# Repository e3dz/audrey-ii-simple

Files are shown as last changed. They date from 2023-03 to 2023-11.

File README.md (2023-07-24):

# Audrey II

Audrey II is a droning horroscape generator instrument for the Daisy Seed + SynthUX Simple platform
based on simple physical modeling principles.

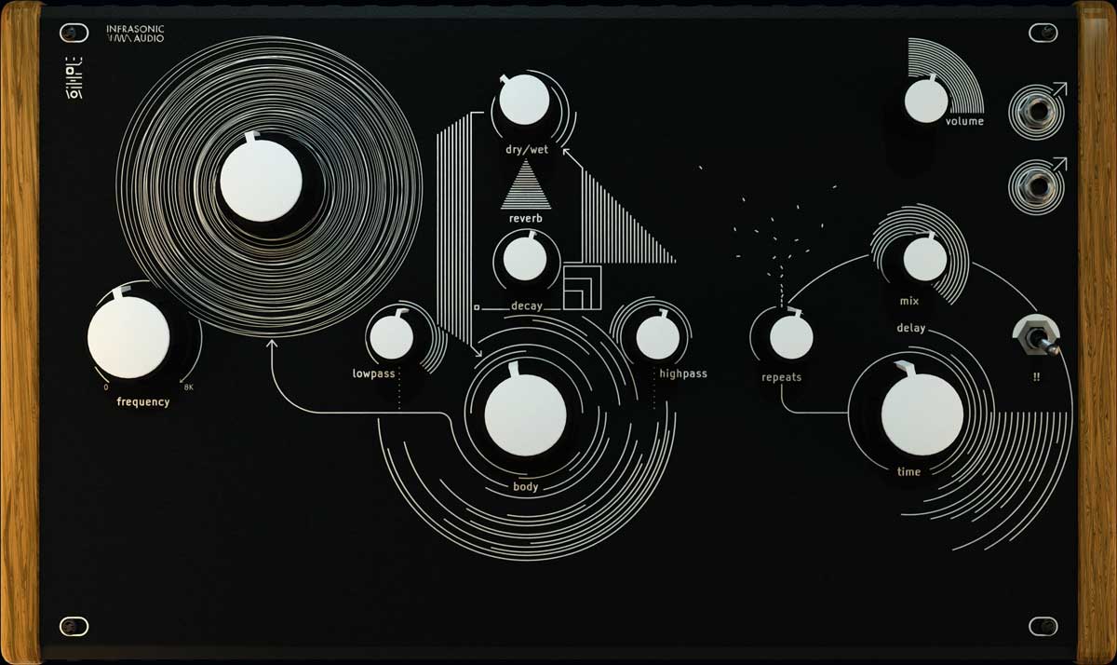
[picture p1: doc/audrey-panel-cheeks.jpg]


_The vortex beckons you. With trembling fingers, you ever so gently turn the mysterious knob within.
Gently, at first, the engine stirs and the arcane beast within awakens. Your pulse quickens.
It wants more. As you turn the knob further, a chilling draft fills the room. The tone swells.
You attempt to appease it with the other controls, but its cries merely evolve into something new,
 equally terrifying and beautiful. A tear rolls down your cheek. The prophecy is fulfilled._

## Overview

At the core of Audrey II is a [Karplus Strong](https://en.wikipedia.org/wiki/Karplus%E2%80%93Strong_string_synthesis)
string model, one of simplest  possible string-waveguide physical modeling implementations.

The output tap of the string model feeds into a soft-clipping distortion, then a reverb,
then into fairly gentle linear lowpass and highpass EQ filters, and then finally into a
longer delay line (aka "body") before being fed back into the string model.

Rather than the typical noise burst or other excitation signals used in "realistic" K-S
models, Audrey-II simply feeds the string a constant stream of inaudible white noise.
As a result, no sound is produced by the instrument until the outer feedback gain is increased
(the big knob with all the circles around it).

This causes the aforementioned feedback loop to activate and a signal begins to build. The
rough fundamental pitch of the sound is determined by the K-S string delay line length
("frequency") and the overtones which resonate and the overall timbre of the sound is
determined by the rest of the controls in the outer feedback loop.

Finally, the output of this section goes through a tape-like delay with a fairly long
maximum delay time and a feedback control designed to deliberately produce infinitely
growing/saturating feedback, for creative distorted warping and warbling possibilities.

## Simple Kit Build Guide

### [🛠️ Build Guide](https://github.com/infrasonicaudio/audrey-ii-simple/wiki/Building-the-Audrey-II-Simple-Kit)

## Flashing the Daisy Seed

The easiest way to program an assembled Audrey II is with a pre-built binary file.
This does not require setting up the toolchain or compiling any code.

1. Download the latest `.bin` file from the [releases page](https://github.com/infrasonicaudio/audrey-ii-simple/releases)
2. Go to the [Daisy Web Programmer](https://electro-smith.github.io/Programmer/) in Google Chrome
3. Connect the Daisy Seed to your computer with a USB cable (double check that the cable you use actually carries data, not just power)
4. Follow the Help instructions at the top to put the Daisy Seed into bootloader mode and connect it to the web programmer
5. In the section labeled "Or select a file from your computer..." click "Browse" and open the `.bin` file you downloaded in step 1
6. At the bottom click "Program" and wait for the process to complete

## Firmware Hacking

1. Install the [Daisy Toolchain](https://github.com/electro-smith/DaisyWiki/wiki/1.-Setting-Up-Your-Development-Environment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) for your operating system
2. Clone this repository and its submodules
3. Open the repository folder in VScode
4. Run the "build_all" task (see: [VSCode tasks](https://code.visualstudio.com/Docs/editor/tasks)). You only have to build_all once to ensure the libraries are built, after that you can do just "build"
5. After a successful build you can flash the Seed using the "program" or "program-dfu" task depending on whether you're using an STLink or DFU over USB

Or if you don't want to use VSCode, you can run standard gnu `make` in the root of `lib/libDaisy`,
`lib/DaisySp` and finally in the repository root. Then you can use `make program` or
`make program-dfu` to flash the built binary.

## License

This project is licensed under the MIT License. See `LICENSE` for details.

This project uses code from DaisySP, libDaisy, RtMidi, and RtAudio which are all
also licensed under the MIT license. The relevant license documentation and
source code for these can be found in `lib/` as git submodules.

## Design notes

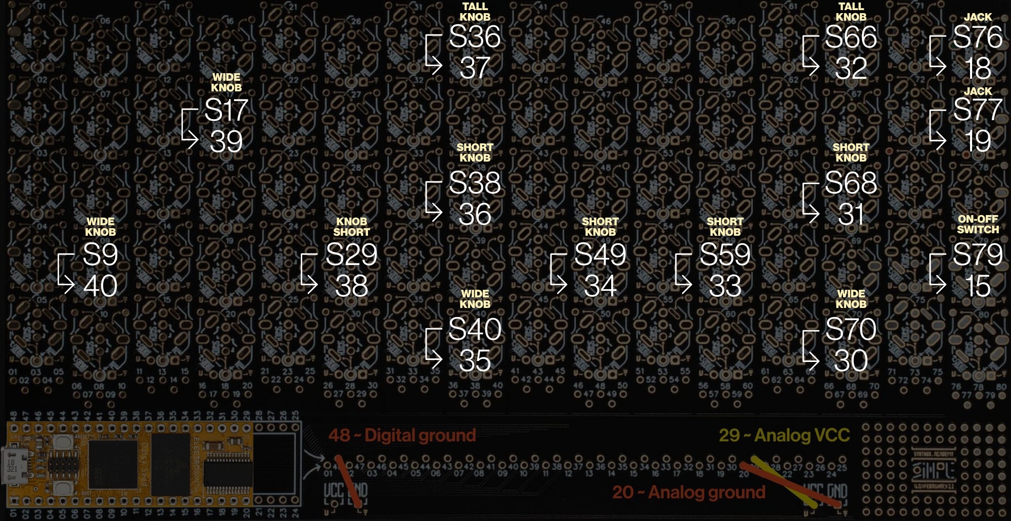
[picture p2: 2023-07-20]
doc/audrey-simple-routing.jpg

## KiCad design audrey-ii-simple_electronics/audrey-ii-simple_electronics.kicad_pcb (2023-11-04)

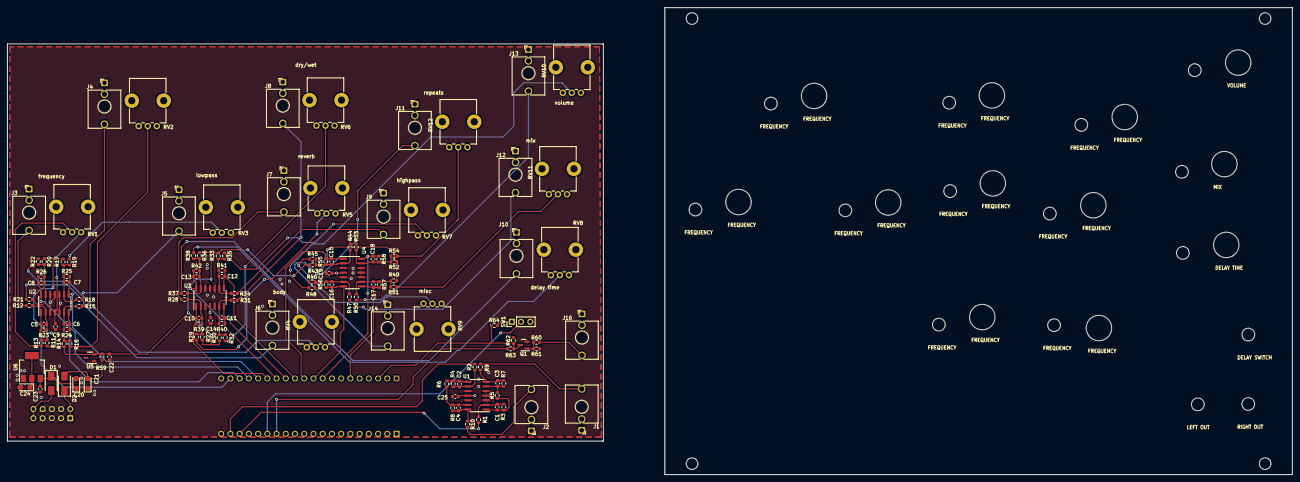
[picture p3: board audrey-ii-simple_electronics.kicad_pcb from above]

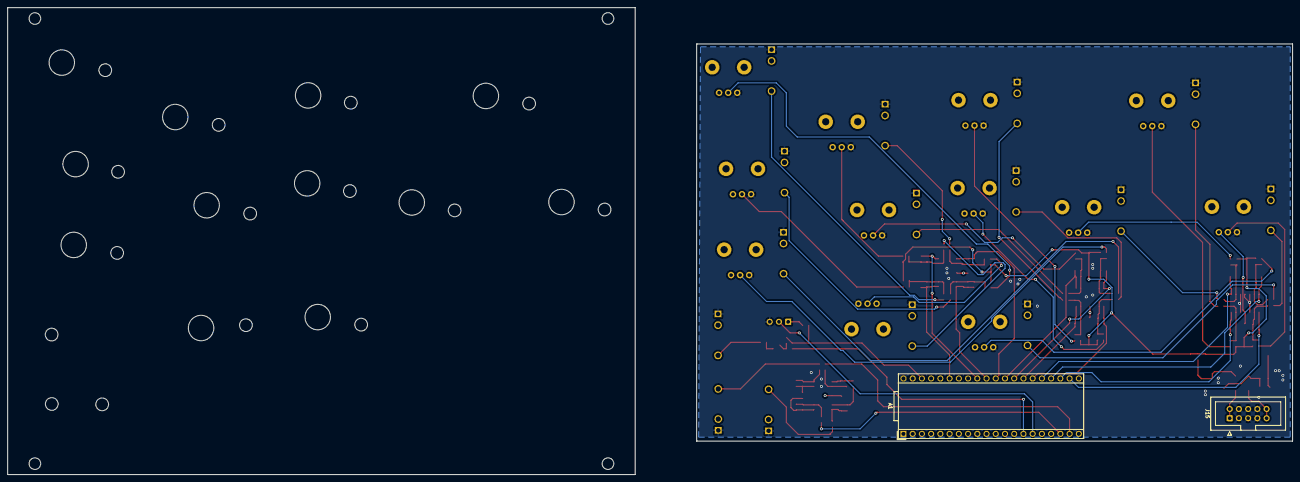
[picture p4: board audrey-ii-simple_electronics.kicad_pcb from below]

Board: 4 copper layers, 164.0 x 109.3 mm, 128 parts (2 on the bottom side), 75 nets.

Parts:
A1: Electrosmith_Daisy_Seed_Rev4; Electrosmith_Daisy_Seed
C1, C2, C3, C4: 47p; C_0603_1608Metric
C5, C6, C7, C8, C10, C11, C12, C13, C15, C16, C17, C18: 10n; C_0603_1608Metric
C9, C14, C19, C22, C23, C25: 100n; C_0603_1608Metric
C20, C21: 22u; CP_EIA-3216-18_Kemet-A
C24: 10uF; CP_EIA-3216-18_Kemet-A
D1, D2: D_Small; D_SMA
J1, J2, J16: DAC_OUT_2; Jack_3.5mm_QingPu_WQP-PJ398SM_Vertical_CircularHoles
J3, J7, J11: CV_1; Jack_3.5mm_QingPu_WQP-PJ398SM_Vertical_CircularHoles
J4, J8, J12: CV_2; Jack_3.5mm_QingPu_WQP-PJ398SM_Vertical_CircularHoles
J5, J9, J13: CV_3; Jack_3.5mm_QingPu_WQP-PJ398SM_Vertical_CircularHoles
J6, J10, J14: CV_4; Jack_3.5mm_QingPu_WQP-PJ398SM_Vertical_CircularHoles
J15: Conn_02x05_Odd_Even; IDC-Header_2x05_P2.54mm_Vertical
Q1: MMBT3904; SOT-23
R1, R2, R62: 10k; R_0603_1608Metric
R3, R4, R5, R6, R7, R8, R12, R15, R18, R21, R28, R31, R34, R37, R44, R47, R50, R53, R60: 100k; R_0603_1608Metric
R9, R10, R63, R64: 1k; R_0603_1608Metric
R11, R14, R17, R20, R27, R30, R33, R36, R43, R46, R49, R52: 200k; R_0603_1608Metric
R13, R16, R19, R22, R23, R24, R25, R26, R29, R32, R35, R38, R39, R40, R41, R42, R45, R48, R51, R54, R55, R56, R57, R58: 66k5; R_0603_1608Metric
R59: 2k; R_0603_1608Metric
R61: 1M; R_0603_1608Metric
RV1, RV2, RV3, RV4, RV5, RV6, RV7, RV8, RV9, RV10, RV11, RV12: M-10K-B-D; Potentiometer_Alps_RK09K_Single_Vertical
SW1: SW_SPDT; PinHeader_1x03_P2.54mm_Vertical
U1: TL074; SOIC-14_3.9x8.7mm_P1.27mm
U2, U3, U4: MCP6004; SOIC-14_3.9x8.7mm_P1.27mm
U5: LM4040-10V; SOT-23-3
U6: LD1117S50TR_SOT223; SOT-223-3_TabPin2

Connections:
+3.3V: A1.38 (3V3_D), R62.2, R64.1
+3.3VA: A1.21 (3V3_A), C9.1, C14.1, C19.1, C25.1, RV1.1, RV2.1, RV3.1, RV4.1, RV5.1, RV6.1, RV7.1, RV8.1, RV9.1, RV10.1, RV11.1, RV12.1, U1.11 (V-), U2.4 (V+), U3.4 (V+), U4.4 (V+)
+5V: C24.1, U6.2 (VO)
-10V_REF: C22.1, R11.1, R14.1, R17.1, R20.1, R27.1, R30.1, R33.1, R36.1, R43.1, R46.1, R49.1, R52.1, R59.1, U5.2 (A)
/ADCBufferIn1/ADC_1: A1.26 (ADC_4), C10.1, R39.2, U3.1
/ADCBufferIn1/ADC_2: A1.27 (ADC_5), C11.1, R40.2, U3.7
/ADCBufferIn1/ADC_3: A1.29 (DAC_OUT2), C12.1, R41.2, U3.8
/ADCBufferIn1/ADC_4: A1.28 (ADC_6), C13.1, R42.2, U3.14
/ADCBufferIn1/KNOB_1: R29.1, RV5.2
/ADCBufferIn1/KNOB_2: R32.1, RV6.2
/ADCBufferIn1/KNOB_3: R35.1, RV7.2
/ADCBufferIn1/KNOB_4: R38.1, RV8.2
/ADCBufferIn2/ADC_1: A1.30 (DAC_OUT1), C15.1, R55.2, U4.1
/ADCBufferIn2/ADC_2: A1.31 (SAI2_MCLK), C16.1, R56.2, U4.7
/ADCBufferIn2/ADC_3: A1.35 (SAI2_SCK), C17.1, R57.2, U4.8
/ADCBufferIn2/ADC_4: A1.32 (SAI2_SD_B), C18.1, R58.2, U4.14
/ADCBufferIn2/KNOB_1: R45.1, RV9.2
/ADCBufferIn2/KNOB_2: R48.1, RV10.2
/ADCBufferIn2/KNOB_3: R51.1, RV11.2
/ADCBufferIn2/KNOB_4: R54.1, RV12.2
/ADCBufferIn/ADC_1: A1.22 (ADC_0), C5.1, R23.2, U2.1
/ADCBufferIn/ADC_2: A1.23 (ADC_1), C6.1, R24.2, U2.7
/ADCBufferIn/ADC_3: A1.25 (ADC_3), C7.1, R25.2, U2.8
/ADCBufferIn/ADC_4: A1.24 (ADC_2), C8.1, R26.2, U2.14
/ADCBufferIn/KNOB_1: R13.1, RV1.2
/ADCBufferIn/KNOB_2: R16.1, RV2.2
/ADCBufferIn/KNOB_3: R19.1, RV3.2
/ADCBufferIn/KNOB_4: R22.1, RV4.2
/Audio Buffer Out/AUDIO_OUT_L: A1.18 (AUDIO_OUT_1), R1.1
/Audio Buffer Out/AUDIO_OUT_R: A1.19 (AUDIO_OUT_2), R2.1
/GPIOIn/In: A1.14 (USART1_TX), R63.1
/SPDT/I/O: A1.15 (USART1_RX), SW1.2 (B)
GND: A1.20 (AGND), A1.40 (DGND), C9.2, C14.2, C19.2, C20.2, C21.1, C22.2, C23.2, C24.2, C25.2, J1.S, J2.S, J3.S, J4.S, J5.S, J6.S, J7.S, J8.S, J9.S, J10.S, J11.S, J12.S, J13.S, J14.S, J15.3, J15.4, J15.5, J15.6, J15.7, J15.8, J16.S, Q1.2 (E), R61.1, RV1.3, RV2.3, RV3.3, RV4.3, RV5.3, RV6.3, RV7.3, RV8.3, RV9.3, RV10.3, RV11.3, RV12.3, SW1.3 (C), U1.3 (+), U1.4 (V+), U1.5 (+), U1.10 (+), U1.12 (+), U2.3 (+), U2.5 (+), U2.10 (+), U2.11 (V-), U2.12 (+), U3.3 (+), U3.5 (+), U3.10 (+), U3.11 (V-), U3.12 (+), U4.3 (+), U4.5 (+), U4.10 (+), U4.11 (V-), U4.12 (+), U5.1 (K), U6.1 (GND)
unnamed: C1.1, R3.2, R5.1, U1.1
unnamed: C2.1, R4.2, R6.1, U1.8
unnamed: C3.1, R7.2, R9.1, U1.7
unnamed: C4.1, R8.2, R10.1, U1.14
unnamed: D1.2 (A), J15.9, J15.10
unnamed: D2.1 (K), J15.1, J15.2
unnamed: J1.T, R9.2
unnamed: J2.T, R10.2
unnamed: J3.T, R12.1
unnamed: J4.T, R15.1
unnamed: J5.T, R18.1
unnamed: J6.T, R21.1
unnamed: J7.T, R28.1
unnamed: J8.T, R31.1
unnamed: J9.T, R34.1
unnamed: J10.T, R37.1
unnamed: J11.T, R44.1
unnamed: J12.T, R47.1
unnamed: J13.T, R50.1
unnamed: J14.T, R53.1
unnamed: J16.T, R60.1
unnamed: Q1.1 (B), R60.2, R61.2
unnamed: Q1.3 (C), R62.1, R63.2
unnamed: R64.2, SW1.1 (A)
unnamed: C1.2, R1.2, R3.1, U1.2 (-)
unnamed: C3.2, R5.2, R7.1, U1.6 (-)
unnamed: C2.2, R2.2, R4.1, U1.9 (-)
unnamed: C4.2, R6.2, R8.1, U1.13 (-)
unnamed: C5.2, R11.2, R12.2, R13.2, R23.1, U2.2 (-)
unnamed: C6.2, R14.2, R15.2, R16.2, R24.1, U2.6 (-)
unnamed: C7.2, R17.2, R18.2, R19.2, R25.1, U2.9 (-)
unnamed: C8.2, R20.2, R21.2, R22.2, R26.1, U2.13 (-)
unnamed: C10.2, R27.2, R28.2, R29.2, R39.1, U3.2 (-)
unnamed: C11.2, R30.2, R31.2, R32.2, R40.1, U3.6 (-)
unnamed: C12.2, R33.2, R34.2, R35.2, R41.1, U3.9 (-)
unnamed: C13.2, R36.2, R37.2, R38.2, R42.1, U3.13 (-)
unnamed: C15.2, R43.2, R44.2, R45.2, R55.1, U4.2 (-)
unnamed: C16.2, R46.2, R47.2, R48.2, R56.1, U4.6 (-)
unnamed: C17.2, R49.2, R50.2, R51.2, R57.1, U4.9 (-)
unnamed: C18.2, R52.2, R53.2, R54.2, R58.1, U4.13 (-)
VCC: C20.1, C23.1, D1.1 (K), U6.3 (VI)
VEE: C21.2, D2.2 (A), R59.2

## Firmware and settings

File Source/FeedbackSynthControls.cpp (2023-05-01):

#include "FeedbackSynthControls.h"
#include <functional>

using namespace infrasonic;
using namespace infrasonic::FeedbackSynth;
using namespace daisy;

////////////// SIMPLE X DAISY PINOUT CHEATSHEET ///////////////

// 3v3           29  |       |   20    AGND
// D15 / A0      30  |       |   19    OUT 01
// D16 / A1      31  |       |   18    OUT 00
// D17 / A2      32  |       |   17    IN 01
// D18 / A3      33  |       |   16    IN 00
// D19 / A4      34  |       |   15    D14
// D20 / A5      35  |       |   14    D13
// D21 / A6      36  |       |   13    D12
// D22 / A7      37  |       |   12    D11
// D23 / A8      38  |       |   11    D10
// D24 / A9      39  |       |   10    D9
// D25 / A10     40  |       |   09    D8
// D26           41  |       |   08    D7
// D27           42  |       |   07    D6
// D28 / A11     43  |       |   06    D5
// D29           44  |       |   05    D4
// D30           45  |       |   04    D3
// 3v3 Digital   46  |       |   03    D2
// VIN           47  |       |   02    D1
// DGND          48  |       |   01    D0

// TODO: Add footprint numbers to these

static constexpr daisy::Pin kFreqKnobAdcPin             = daisy::seed::A10; // Simple bottom pin 40
static constexpr daisy::Pin kFeedbackGainKnobPin        = daisy::seed::A9;  // Simple bottom pin 39
static constexpr daisy::Pin kFeedbackBodyKnobPin        = daisy::seed::A5;  // Simple bottom pin 35
static constexpr daisy::Pin kFeedbackLowpassKnobAdcPin  = daisy::seed::A8;  // Simple bottom pin 38
static constexpr daisy::Pin kFeedbackHighpassKnobAdcPin = daisy::seed::A4;  // Simple bottom pin 34
static constexpr daisy::Pin kRevMixKnobAdcPin           = daisy::seed::A7;  // Simple bottom pin 37
static constexpr daisy::Pin kRevDecayKnobAdcPin         = daisy::seed::A6;  // Simple bottom pin 36
static constexpr daisy::Pin kEchoSendKnobAdcPin         = daisy::seed::A1;  // Simple bottom pin 31
static constexpr daisy::Pin kEchoTimeKnobAdcPin         = daisy::seed::A0;  // Simple bottom pin 30
static constexpr daisy::Pin kEchoFeedbackKnobAdcPin     = daisy::seed::A3;  // Simple bottom pin 33
static constexpr daisy::Pin kOutputVolumeAdcPin         = daisy::seed::A2;  // Simple bottom pin 32
static constexpr daisy::Pin kDelaySwitchPin             = daisy::seed::D14; // Simple bottom pin 15

void Controls::Init(DaisySeed &hw, Engine &engine) {
    params_.Init(hw.AudioSampleRate() / hw.AudioBlockSize());
    del_sw_.Init(
        static_cast<dsy_gpio_pin>(kDelaySwitchPin),
        1000.0f,
        Switch::TYPE_TOGGLE,
        Switch::POLARITY_INVERTED,
        Switch::PULL_UP
    );
    initADCs(hw);
    registerParams(engine);
}

void Controls::Update(DaisySeed &hw) {
    params_.UpdateNormalized(Parameter::Frequency,          1.0f - hw.adc.GetFloat(0));
    params_.UpdateNormalized(Parameter::FeedbackGain,       1.0f - hw.adc.GetFloat(1));
    params_.UpdateNormalized(Parameter::FeedbackBody,       1.0f - hw.adc.GetFloat(2));
    params_.UpdateNormalized(Parameter::FeedbackLPFCutoff,  1.0f - hw.adc.GetFloat(3));
    params_.UpdateNormalized(Parameter::FeedbackHPFCutoff,  1.0f - hw.adc.GetFloat(4));
    params_.UpdateNormalized(Parameter::ReverbMix,          1.0f - hw.adc.GetFloat(5));
    // Special mapping for reverb feedback/decay (anti-exponential tension curve)
    params_.UpdateNormalized(Parameter::ReverbDecay,        ftension(1.0f - hw.adc.GetFloat(6), -3.0f));
    params_.UpdateNormalized(Parameter::EchoDelaySend,      1.0f - hw.adc.GetFloat(7));
    // Delay switch doubles or halves delay time instantly for doppler warp
    del_sw_.Debounce();
    float delay_norm = 1.0f - hw.adc.GetFloat(8);
    float delay_scale = del_sw_.Pressed() ? 0.5f : 1.0f;
    params_.UpdateNormalized(Parameter::EchoDelayTime, delay_norm * delay_scale);
    params_.UpdateNormalized(Parameter::EchoDelayFeedback,  1.0f - hw.adc.GetFloat(9));
    params_.UpdateNormalized(Parameter::OutputVolume,       1.0f - hw.adc.GetFloat(10));
}

void Controls::initADCs(DaisySeed &hw) {
    AdcChannelConfig config[kNumAdcChannels];

    config[0].InitSingle(kFreqKnobAdcPin);
    config[1].InitSingle(kFeedbackGainKnobPin);
    config[2].InitSingle(kFeedbackBodyKnobPin);
    config[3].InitSingle(kFeedbackLowpassKnobAdcPin);
    config[4].InitSingle(kFeedbackHighpassKnobAdcPin);
    config[5].InitSingle(kRevMixKnobAdcPin);
    config[6].InitSingle(kRevDecayKnobAdcPin);
    config[7].InitSingle(kEchoSendKnobAdcPin);
    config[8].InitSingle(kEchoTimeKnobAdcPin);
    config[9].InitSingle(kEchoFeedbackKnobAdcPin);
    config[10].InitSingle(kOutputVolumeAdcPin);

    hw.adc.Init(config, kNumAdcChannels);
    hw.adc.Start();
}

void Controls::registerParams(Engine &engine) {
    using namespace std::placeholders;

    // String freq/pitch as note number
    params_.Register(Parameter::Frequency, 40.0f, 16.0f, 72.0f,
        std::bind(&Engine::SetStringPitch, &engine, _1), 0.2f);

    // Feedback Gain in dbFS
    params_.Register(Parameter::FeedbackGain, -60.0f, -60.0f, 12.0f,
        std::bind(&Engine::SetFeedbackGain, &engine, _1));

    // Feedback body/delay in seconds
    params_.Register(Parameter::FeedbackBody, 0.001f, 0.001f, 0.1f,
        std::bind(&Engine::SetFeedbackDelay, &engine, _1), 1.0f, daisysp::Mapping::EXP);

    // Feedback filter cutoffs in hz
    params_.Register(Parameter::FeedbackLPFCutoff, 18000.0f, 100.0f, 18000.0f,
        std::bind(&Engine::SetFeedbackLPFCutoff, &engine, _1), 0.05f, daisysp::Mapping::LOG);
    params_.Register(Parameter::FeedbackHPFCutoff, 250.0f, 10.0f, 4000.0f,
        std::bind(&Engine::SetFeedbackHPFCutoff, &engine, _1), 0.05f, daisysp::Mapping::LOG);

    // Reverb Mix
    params_.Register(Parameter::ReverbMix, 0.0f, 0.0f, 1.0f,
        std::bind(&Engine::SetReverbMix, &engine, _1));

    // Reverb Feedback (input is mapped to anti-exponential on ADC read)
    params_.Register(Parameter::ReverbDecay, 0.2f, 0.2f, 1.0f,
        std::bind(&Engine::SetReverbFeedback, &engine, _1));

    // Echo Delay send
    params_.Register(Parameter::EchoDelaySend, 0.0f, 0.0f, 1.0f,
        std::bind(&Engine::SetEchoDelaySendAmount, &engine, _1), 0.05f, daisysp::Mapping::EXP);

    // Echo Delay time in s
    params_.Register(Parameter::EchoDelayTime, 0.5f, 0.05f, 5.0f,
        std::bind(&Engine::SetEchoDelayTime, &engine, _1), 0.1f, daisysp::Mapping::EXP);

    // Echo Delay feedback
    params_.Register(Parameter::EchoDelayFeedback, 0.0f, 0.0f, 1.5f,
        std::bind(&Engine::SetEchoDelayFeedback, &engine, _1));

    // Output level
    params_.Register(Parameter::OutputVolume, 0.5f, 0.0f, 1.0f,
        std::bind(&Engine::SetOutputLevel, &engine, _1), 0.05f, daisysp::Mapping::EXP);
}

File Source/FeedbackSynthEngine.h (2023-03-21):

#pragma once
#ifndef IFS_FEEDBACK_SYNTH_ENGINE_H
#define IFS_FEEDBACK_SYNTH_ENGINE_H

#include <memory>
#include <daisysp.h>
#include "BiquadFilters.h"
#include "EchoDelay.h"
#include "KarplusString.h"

#ifdef __arm__
#include <dev/sdram.h>
#endif

namespace infrasonic {
namespace FeedbackSynth {

class Engine {

    public:
        Engine() = default;
        ~Engine() = default;

        void Init(const float sample_rate);

        void SetStringPitch(const float nn);

        void SetFeedbackGain(const float gain_dbfs);

        void SetFeedbackDelay(const float delay_s);
        void SetFeedbackLPFCutoff(const float cutoff_hz);
        void SetFeedbackHPFCutoff(const float cutoff_hz);

        void SetEchoDelayTime(const float echo_time);
        void SetEchoDelayFeedback(const float echo_fb);
        void SetEchoDelaySendAmount(const float echo_send);

        // Both range 0-1
        void SetReverbMix(const float mix);
        void SetReverbFeedback(const float time);

        void SetOutputLevel(const float level);

        void Process(float in, float &outL, float &outR);

    private:
        // long enough for 250ms at 48kHz
        static constexpr size_t kMaxFeedbackDelaySamp = 12000;
        // long enough for 5s at 48kHz
        static constexpr size_t kMaxEchoDelaySamp = 48000 * 5;

        float sample_rate_;
        float fb_gain_ = 0.0f;
        float echo_send_ = 0.0f;
        float verb_mix_ = 0.0f;
        float output_level_ = 0.5f;

        float fb_delay_smooth_coef_;
        float fb_delay_samp_ = 1000.f;
        float fb_delay_samp_target_ = 64.f;

        infrasonic::KarplusString strings_[2];
        daisysp::WhiteNoise noise_;
        daisysp::DelayLine<float, kMaxFeedbackDelaySamp> fb_delayline_[2];
        daisysp::Overdrive overdrive_[2];

        LPF12 fb_lpf_;
        HPF12 fb_hpf_;

        using VerbPtr = std::unique_ptr<daisysp::ReverbSc>;
        VerbPtr verb_;

        using EchoDelayPtr = std::unique_ptr<EchoDelay<kMaxEchoDelaySamp>>;
        EchoDelayPtr echo_delay_[2];

        Engine(const Engine &other) = delete;
        Engine(Engine &&other) = delete;
        Engine& operator=(const Engine &other) = delete;
        Engine& operator=(Engine &&other) = delete;
};

}
}

#endif

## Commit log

2023-03-21 Define pin numbers/params for SB version
2023-05-01 Add switch to half delay time (SB mapping)
2023-10-31 added electronics
    [ADCBufferIn.kicad_sch, AudioBufferOut.kicad_sch, GPIOIn.kicad_sch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]
2023-11-04 front panel
    [audrey-ii-simple_electronics.kicad_pcb]
